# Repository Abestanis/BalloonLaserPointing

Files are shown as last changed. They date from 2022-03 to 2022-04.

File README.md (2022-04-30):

# Balloon Laser Pointing

This project is the first iteration of a laser pointing system developed as part of the
stratospheric balloon project of the M2 TSI masters at Paul Sabatier 3 University, Toulouse. 
It consists of software and structure for a two motor platform that allows to point
a laser at another balloon. The laser could then be used for communication, which is not
part of this project.

## Launch

The project was tested during the launch of a stratospheric balloon on the 23rd March 2022.
The system successfully demonstrated its pointing capabilities, although with an offset due
to calibration inaccuracies. 

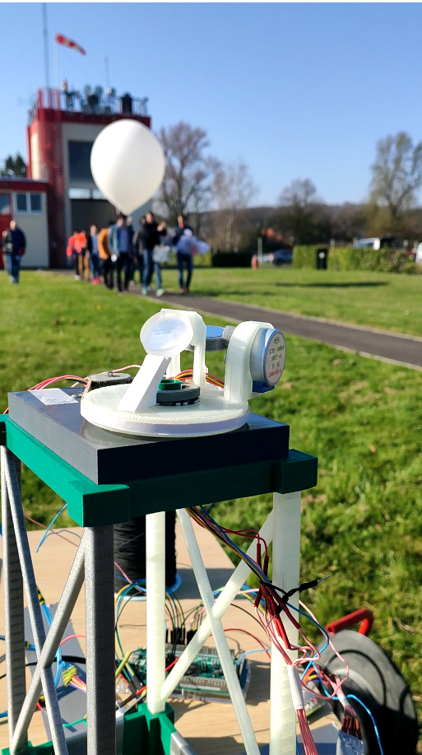
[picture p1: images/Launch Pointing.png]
Pointing during the launch aof a stratospheric balloon


## Building

The project is based on [PlatformIO](https://platformio.org). To build the project, the
[PlatformIO command line tools](https://docs.platformio.org/en/latest/core/installation.html)
are required to be installed.

Run the following commands in the top level directory of the project
(the one containing this README and the [platformio.ini](platformio.ini) file).

Initialize the project and install the dependencies:
```shell
pio project init
pio lib install
```

Build the project:
```shell
pio run
```

Build and upload the project to a connected Arduino Due:
```shell
pio run --target upload
```

## Repository structure

* [`controller`](controller): Contains the controller program that can be used to control
                              the pointing system from a computer via a serial connection.
* [`images`](images): Images used for documentation.
* [`include`](include): C/C++ header files.
* [`lib`](lib): Project specific private libraries.
* [`models`](models): The 3D models of the laser pointing structure.
* [`src`](src): The C/C++ source files containing the code of the project.
* [`platformio.ini`](platformio.ini): [PlatformIO configuration file][platformio_config].

[platformio_config]: https://docs.platformio.org/en/stable/projectconf/index.html#projectconf

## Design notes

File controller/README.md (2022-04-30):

# Controller

This directory contains a controller software that can be run on any computer which is connected
to the Arduino Due via a serial connection.

The software allows sending telecommands and to forward received GPS locations
to the Arduino.

### Dependencies

Install the dependencies with
[pip](https://packaging.python.org/en/latest/tutorials/installing-packages/#use-pip-for-installing):

```shell
pip install -r requirements.txt
```

### Running

To run the controller, start the [controller.py](controller.py) script with Python:

```shell
controller.py
```

### Telecommands

| Name | Arguments | Description |
|---|---|---|
| PING | _None_ | Send a PING, expect a PONG back. |
| GPS | latitude, longitude, altitude | Set the GPS position of the pointing target. |
| CALIBRATE_MOTORS | _None_ | Trigger the automatic calibration of the motors. |
| SET_LOCATION | latitude, longitude, altitude, orientation | Set the position and zero pointing orientation of the structure. |
| SET_MOTOR_POSITION | motor, angle | Manually set the motor position to a specific angle. |
| SET_CALIBRATION_POINT | motor | Set the calibration angle of a motor to the current angle. |

### GPS forwarding
There can be two GPS receivers connected, whose received locations will be logged.
One of the two receivers can be selected as a target in the UI.
The locations received from this GPS receiver will then be forwarded to the Arduino.

### User Interface
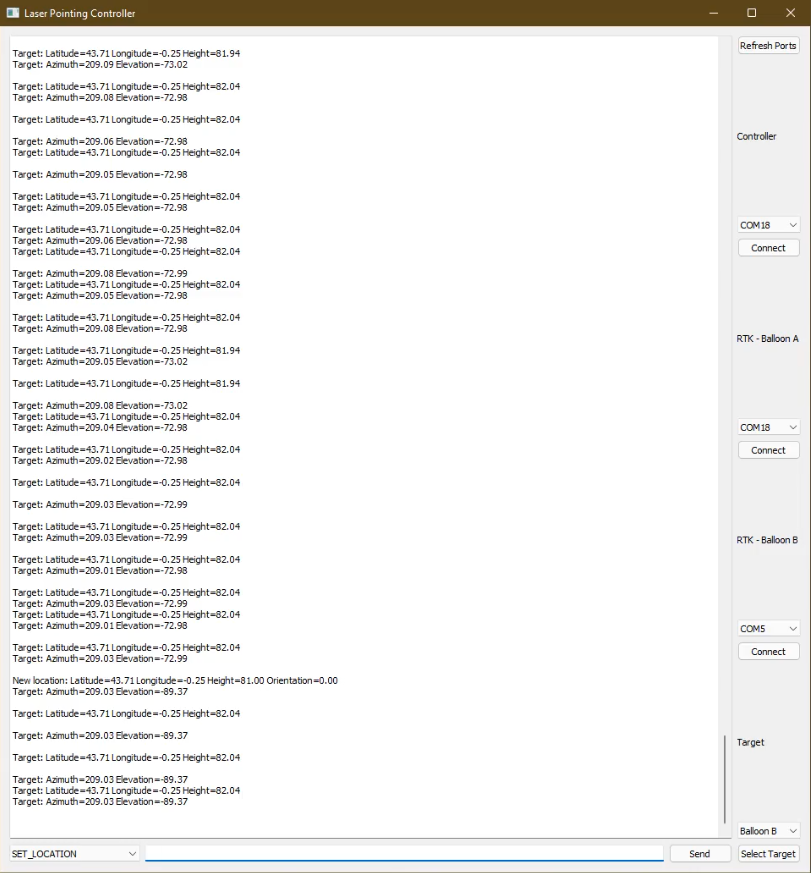
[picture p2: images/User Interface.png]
User interface screenshot


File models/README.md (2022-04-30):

# Models of the structure of the pointing system

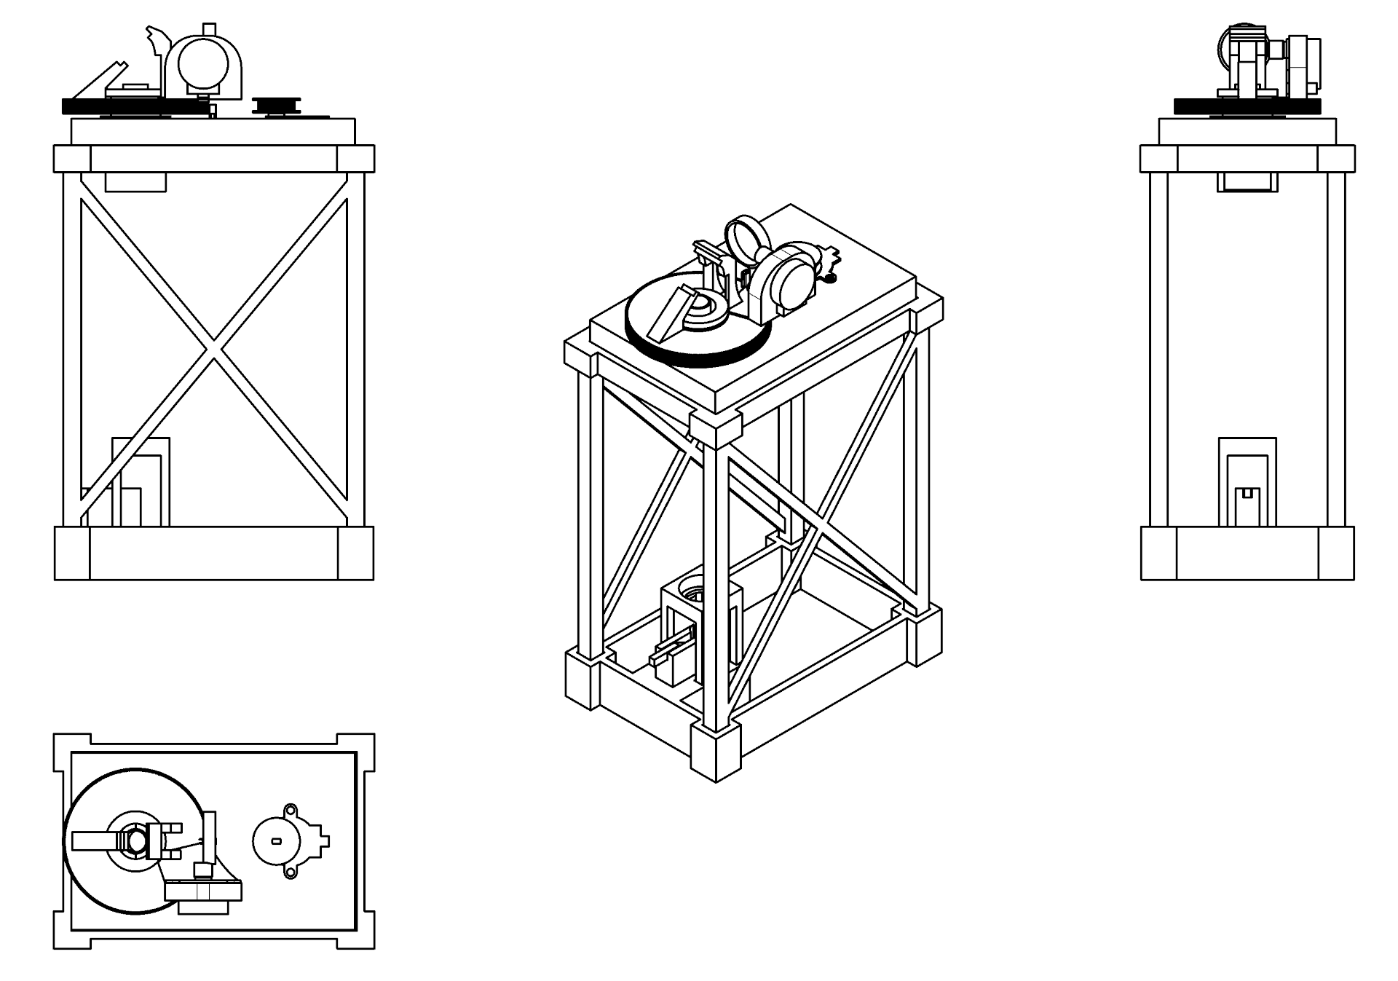
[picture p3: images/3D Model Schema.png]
The schematic of the laser pointing structure


This directory contains 3D models of all components developed for the laser pointing structure.

### Full model

The [full model](Full%20Model.stl) contains all models assembled together.

| Model | Real |
|---|---|
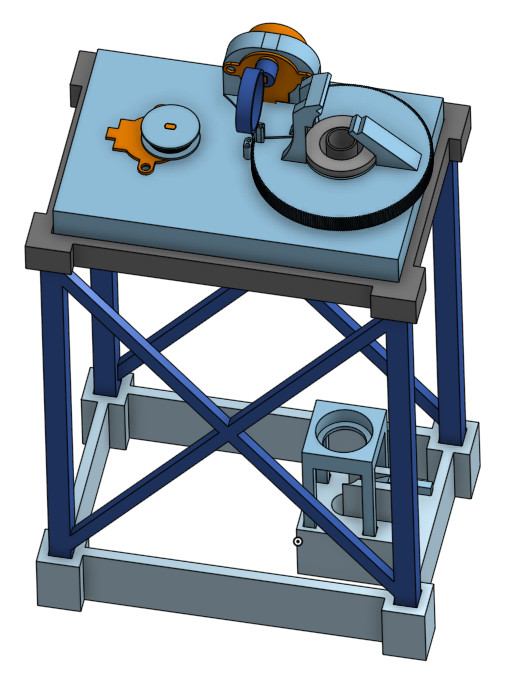
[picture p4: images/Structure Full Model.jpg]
The 3D Model of the fully assembled structure
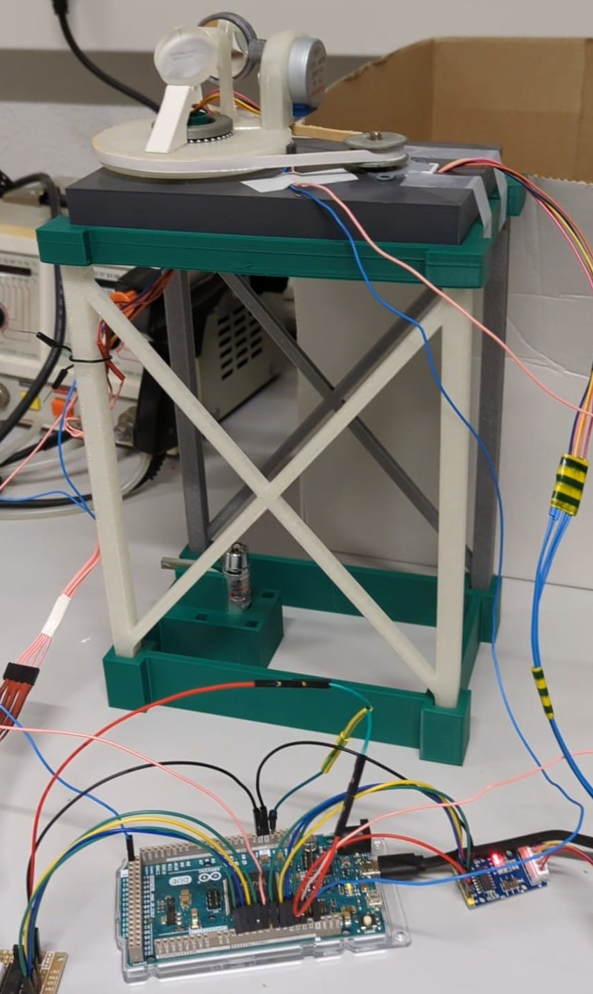
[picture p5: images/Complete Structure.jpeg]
The fully assembled structure
|  |  |

### Motor

This is a placeholder for the [actual motors][Motor Datasheet].

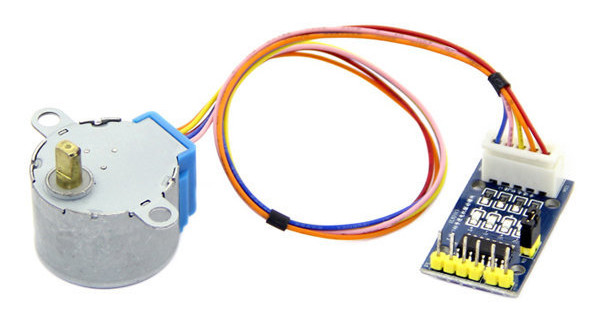
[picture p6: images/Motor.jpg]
The 28BYJ-48-08 5 Vdc motor used in the pointing system


[Motor Datasheet]: https://www.digikey.fr/fr/datasheets/mikroelektronika/mikroelektronika-step-motor-5v-28byj48-datasheet

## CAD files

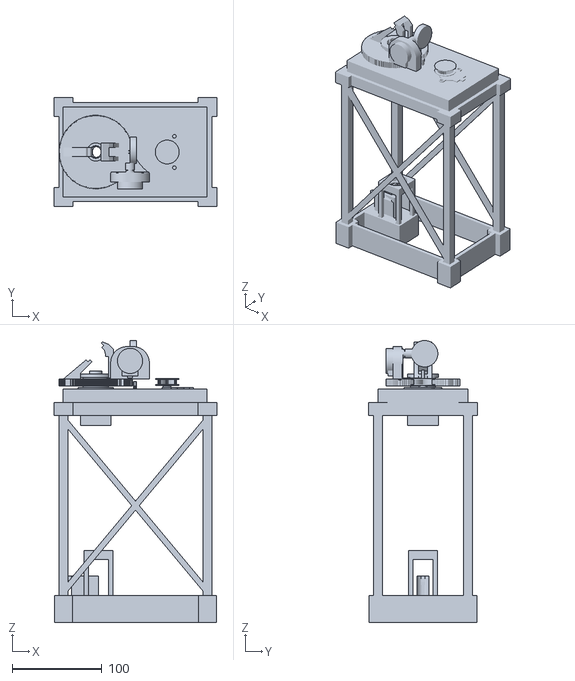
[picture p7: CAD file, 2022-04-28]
models/Full Model.stl
181.0 x 121.0 x 313.7

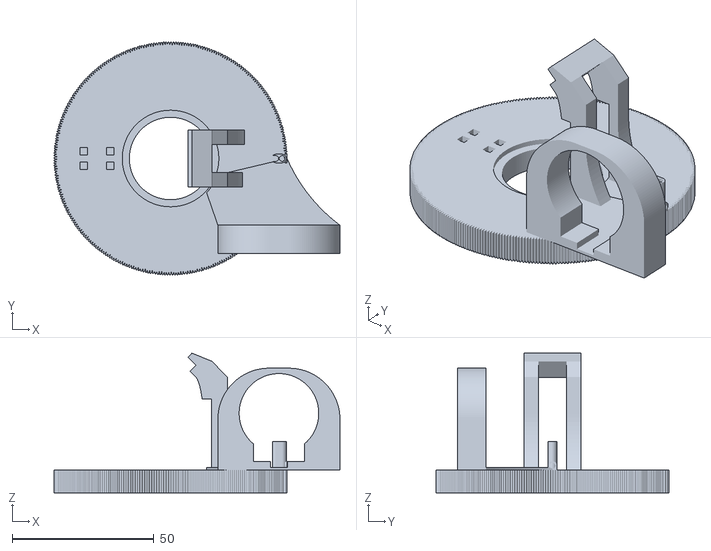
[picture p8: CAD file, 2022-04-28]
models/Main Gear.stl
100.7 x 82.1 x 49.2

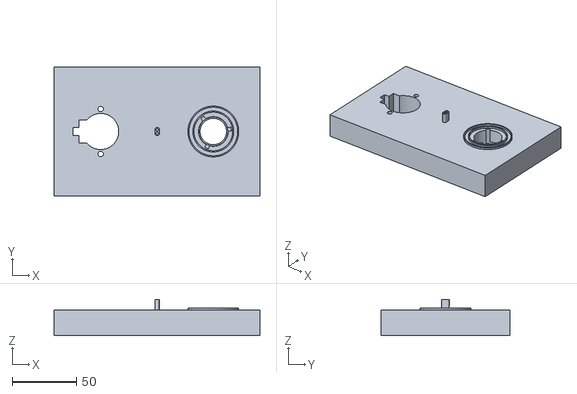
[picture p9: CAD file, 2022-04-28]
models/Motor Base.stl
160.0 x 100.0 x 28.0

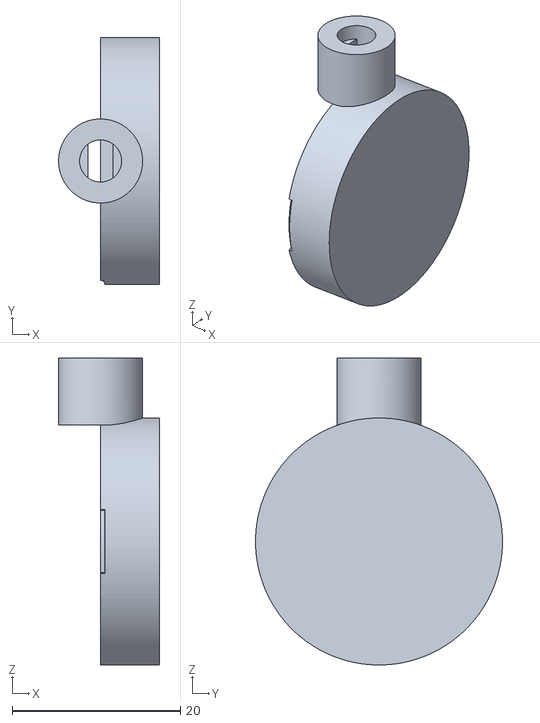
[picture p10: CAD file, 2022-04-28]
models/Mirror Ring Holder.stl
12.0 x 29.4 x 36.5

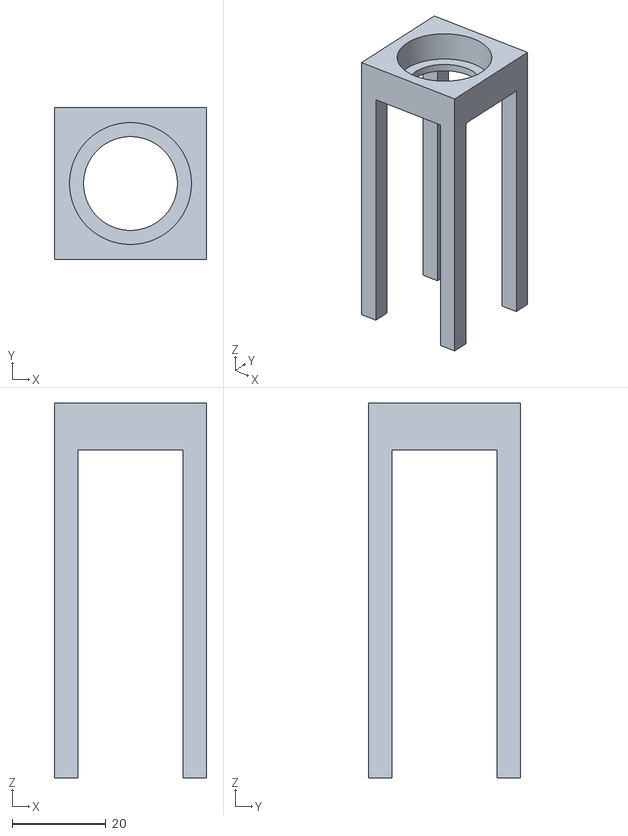
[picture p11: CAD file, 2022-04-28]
models/Lens Holder.stl
32.5 x 32.5 x 80.0

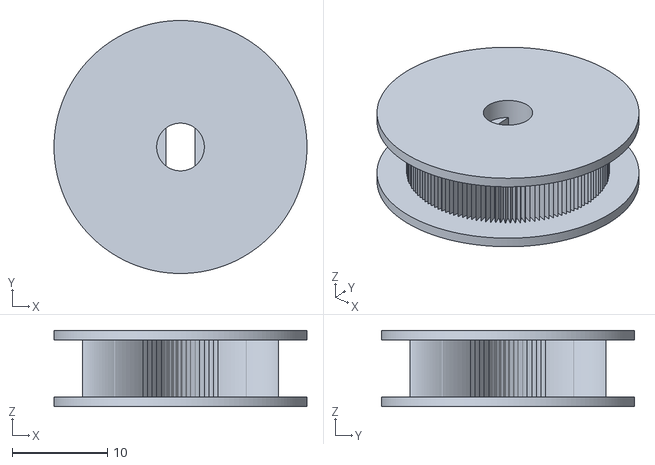
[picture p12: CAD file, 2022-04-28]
models/Small Gear.stl
26.5 x 26.5 x 8.00

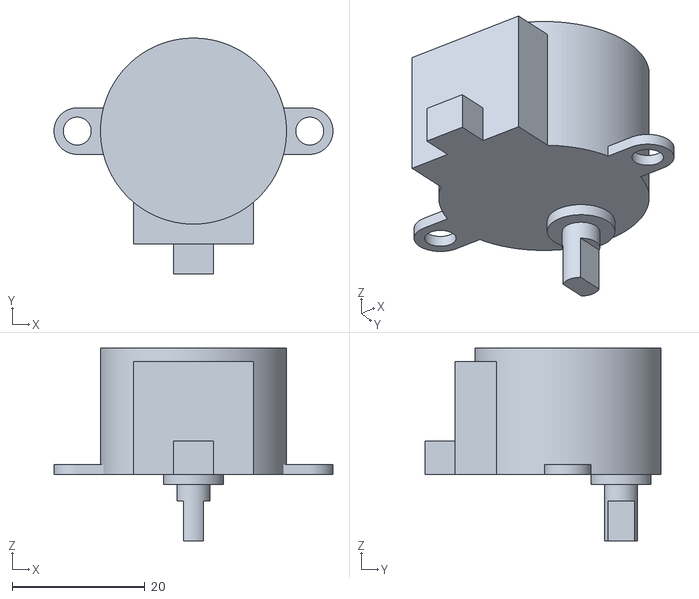
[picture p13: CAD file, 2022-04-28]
models/Motor.stl
42.0 x 35.5 x 29.0

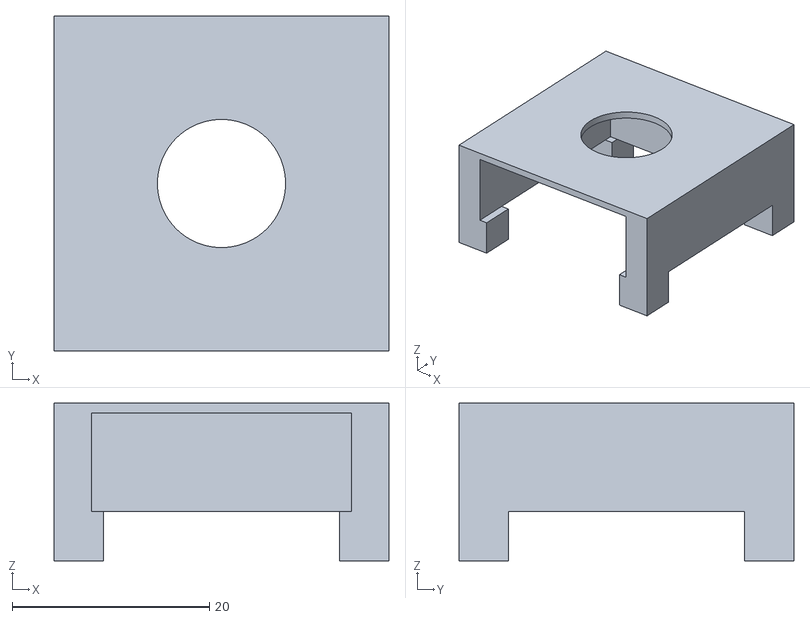
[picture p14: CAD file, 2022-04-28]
models/Lens Box.stl
34.0 x 34.0 x 16.0

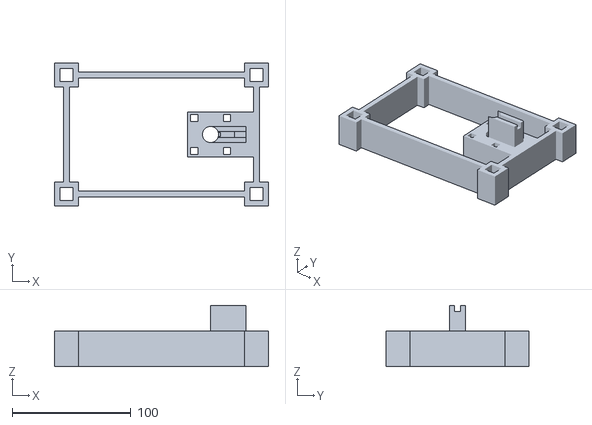
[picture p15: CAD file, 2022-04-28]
models/Base.stl
180.0 x 120.0 x 51.5

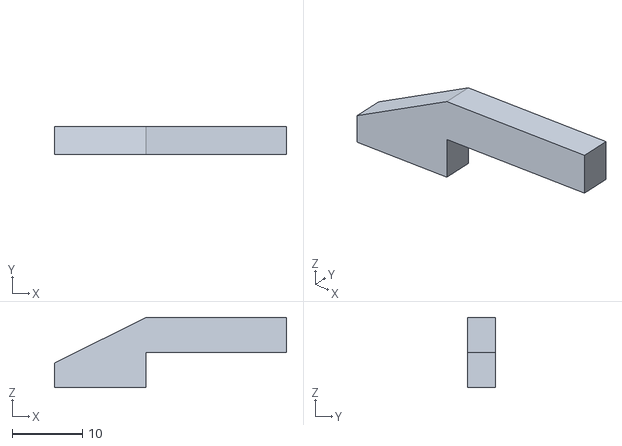
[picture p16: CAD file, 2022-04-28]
models/Laser Button Pusher.stl
33.1 x 4.00 x 10.0

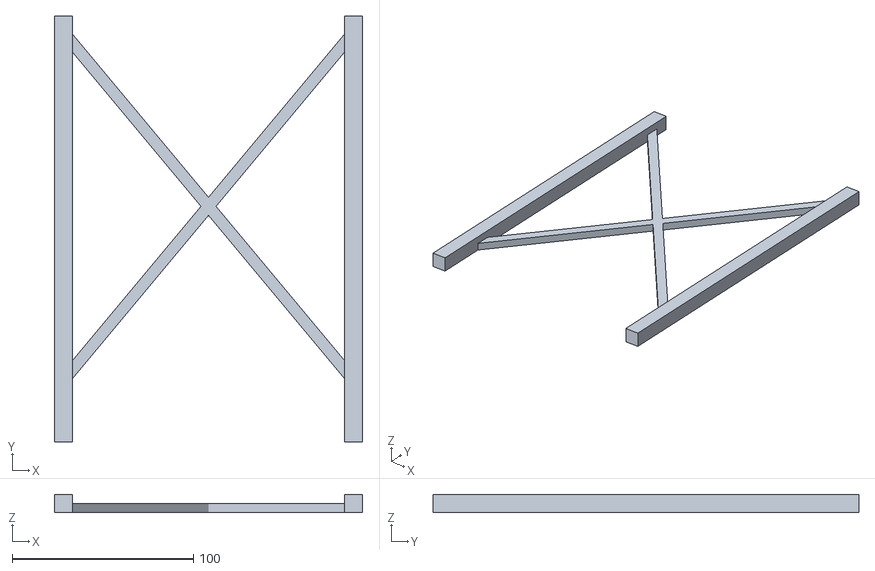
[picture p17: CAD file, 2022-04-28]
models/Pillar.stl
170.0 x 235.0 x 10.0

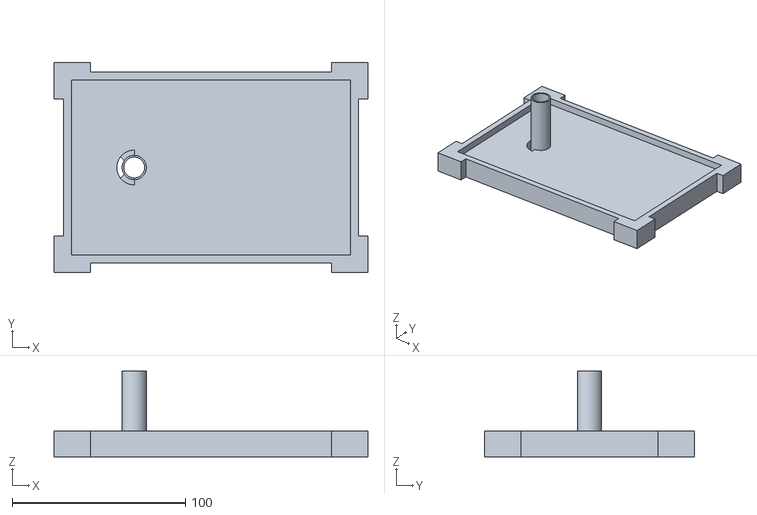
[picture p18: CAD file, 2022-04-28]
models/Top Base.stl
181.0 x 121.0 x 49.5

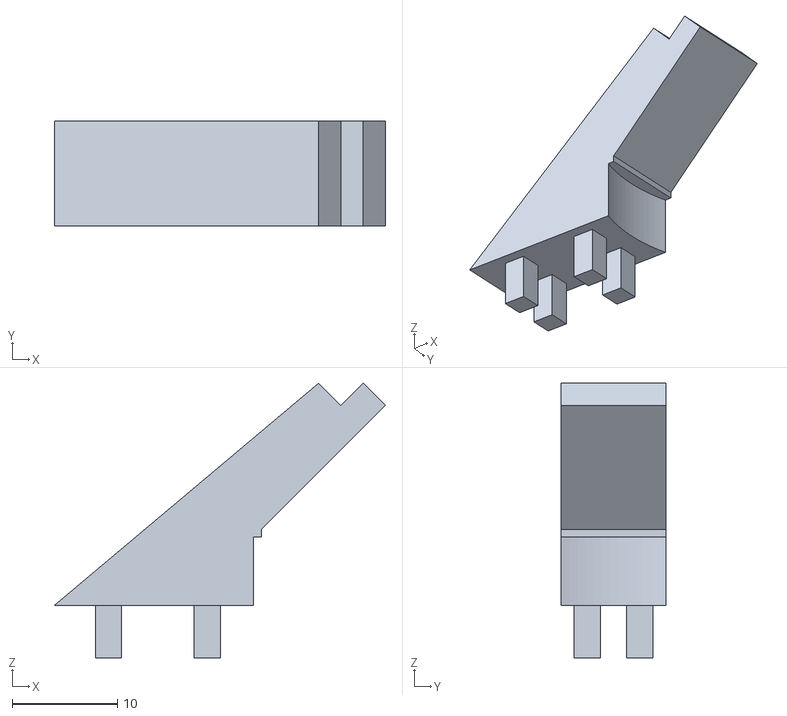
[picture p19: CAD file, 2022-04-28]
models/Mirror Holder 1.stl
31.5 x 10.0 x 26.1

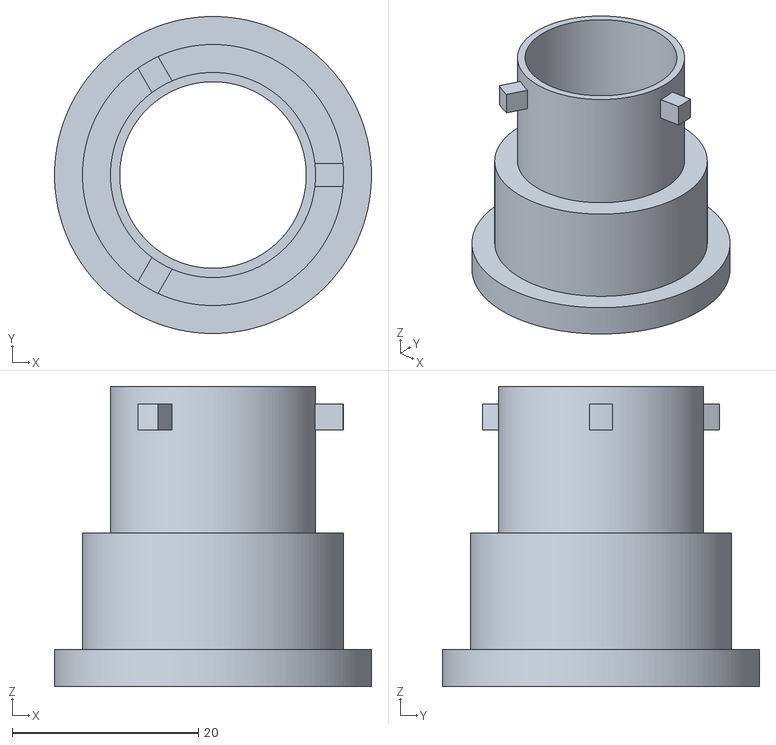
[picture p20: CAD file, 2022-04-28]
models/Gear Bolt.stl
34.0 x 34.0 x 32.2

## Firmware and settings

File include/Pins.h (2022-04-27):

/**
 * This keeps track of all pins used.
 */

#pragma once

#include <cstdint>

/**
 * A physical pin on the Arduino.
 */
class Pin {
public:
    /**
     * Create a new pin from the raw pin number.
     *
     * @param pinNumber The raw number of the pin.
     */
    explicit constexpr Pin(uint32_t pinNumber) : pinNumber(pinNumber) {
    }

    /**
     * The raw number of the pin.
     */
    const uint32_t pinNumber;
};

/**
 * All pins used in the system.
 */
class Pins {
public:
    /**
     * The first pin to control the base motor.
     */
    static constexpr Pin baseMotor1 = Pin(8);

    /**
     * The second pin to control the base motor.
     */
    static constexpr Pin baseMotor2 = Pin(9);

    /**
     * The third pin to control the base motor.
     */
    static constexpr Pin baseMotor3 = Pin(10);

    /**
     * The fourth pin to control the base motor.
     */
    static constexpr Pin baseMotor4 = Pin(11);

    /**
     * The pin indicating the 0° angle position for the base motor.
     */
    static constexpr Pin baseMotorCalibration = Pin(12);

    /**
     * The first pin to control the motor.
     */
    static constexpr Pin elevationMotor1 = Pin(3);

    /**
     * The second pin to control the elevation motor.
     */
    static constexpr Pin elevationMotor2 = Pin(4);

    /**
     * The third pin to control the elevation motor.
     */
    static constexpr Pin elevationMotor3 = Pin(5);

    /**
     * The fourth pin to control the elevation motor.
     */
    static constexpr Pin elevationMotor4 = Pin(6);

    /**
     * The pin indicating the 0° angle position for the elevation motor.
     */
    static constexpr Pin elevationMotorCalibration = Pin(7);
};

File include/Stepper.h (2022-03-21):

/**
 * A class to control a four wire stepper motor, based on the Stepper library for Wiring/Arduino.
 * Original header is included below:
 *
 * Stepper.h - Stepper library for Wiring/Arduino - Version 1.1.0
 *
 * Original library        (0.1)   by Tom Igoe.
 * Two-wire modifications  (0.2)   by Sebastian Gassner
 * Combination version     (0.3)   by Tom Igoe and David Mellis
 * Bug fix for four-wire   (0.4)   by Tom Igoe, bug fix from Noah Shibley
 * High-speed stepping mod         by Eugene Kozlenko
 * Timer rollover fix              by Eugene Kozlenko
 * Five phase five wire    (1.1.0) by Ryan Orendorff
 *
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
 *
 * Drives a unipolar, bipolar, or five phase stepper motor.
 *
 * When wiring multiple stepper motors to a microcontroller, you quickly run
 * out of output pins, with each motor requiring 4 connections.
 *
 * By making use of the fact that at any time two of the four motor coils are
 * the inverse of the other two, the number of control connections can be
 * reduced from 4 to 2 for the unipolar and bipolar motors.
 *
 * A slightly modified circuit around a Darlington transistor array or an
 * L293 H-bridge connects to only 2 microcontroler pins, inverts the signals
 * received, and delivers the 4 (2 plus 2 inverted ones) output signals
 * required for driving a stepper motor. Similarly the Arduino motor shields
 * 2 direction pins may be used.
 *
 * The sequence of control signals for 5 phase, 5 control wires is as follows:
 *
 * Step C0 C1 C2 C3 C4
 *    1  0  1  1  0  1
 *    2  0  1  0  0  1
 *    3  0  1  0  1  1
 *    4  0  1  0  1  0
 *    5  1  1  0  1  0
 *    6  1  0  0  1  0
 *    7  1  0  1  1  0
 *    8  1  0  1  0  0
 *    9  1  0  1  0  1
 *   10  0  0  1  0  1
 *
 * The sequence of control signals for 4 control wires is as follows:
 *
 * Step C0 C1 C2 C3
 *    1  1  0  1  0
 *    2  0  1  1  0
 *    3  0  1  0  1
 *    4  1  0  0  1
 *
 * The sequence of controls signals for 2 control wires is as follows
 * (columns C1 and C2 from above):
 *
 * Step C0 C1
 *    1  0  1
 *    2  1  1
 *    3  1  0
 *    4  0  0
 *
 * The circuits can be found at
 *
 * http://www.arduino.cc/en/Tutorial/Stepper
 */

#pragma once

#include <cstdint>
#include <vector>
#include <DueTimer.h>
#include "units.h"
#include "Pins.h"


/**
 * A stepper motor that can freely rotate in 360 degrees.
 */
class Stepper {
public:

    /**
     * Initialize a stepper motor and start the calibration routine.
     *
     * @param numberOfSteps The number of steps that the motor can take per revolution.
     * @param stepDelay The delay between steps in microseconds.
     * @param motorPin1 The pin number of the first connection to the motor.
     * @param motorPin2 The pin number of the second connection to the motor.
     * @param motorPin3 The pin number of the third connection to the motor.
     * @param motorPin4 The pin number of the fourth connection to the motor.
     * @param calibrationPin The pin number used for calibration of the zero angle of the motor.
     */
    Stepper(unsigned int numberOfSteps, unsigned long stepDelay, Pin motorPin1, Pin motorPin2,
            Pin motorPin3, Pin motorPin4, Pin calibrationPin);

    /**
     * Stop and destruct the motor.
     */
    ~Stepper();

    /**
     * Set the target angle of the motor.
     *
     * @note The function will block until the motor reached the target angle.
     * @param angle The target angle in degrees.
     */
    void setTargetAngle(deg_t angle);

    /**
     * Asynchronously determine the reference step (0° angle) of the motor.
     */
    void calibrate();

    /**
     * Set the current orientation as the calibration point.
     */
    void setCurrentAsCalibrationPoint();

private:
    /**
     * Timer handler that updates the current step towards the target step.
     */
    static void updateMotors();

    /**
     * Update the motor and advance to the next step towards the target step.
     */
    void updateStep();

    /**
     * Set the current step of the motor.
     *
     * @param step The step to step to.
     */
    void setStep(unsigned int step);

    /**
     * Convert an angle in degrees to the corresponding step.
     *
     * @param angle The angle in degrees.
     * @return The step corresponding to the angle.
     */
    unsigned int getStepForAngle(deg_t angle) const;

    /**
     * The delay in microseconds between steps.
     */
    unsigned long stepDelay;

    /**
     * The total number of steps that the motor can take.
     */
    unsigned int totalSteps;

    /**
     * The angle that the motor should point to in degrees.
     */
    deg_t targetAngle = deg_t(0);

    /**
     * The step of the motor that is targeted by the targetAngle.
     */
    unsigned int targetStep = 0;

    /**
     * The current step the motor is on.
     */
    unsigned int currentStep = 0;

    /**
     * Reference step for an angle of zero.
     */
    unsigned int referenceStep;

    /**
     * The current step when the calibration was requested.
     */
    unsigned int calibrationStartStep = 0;

    /**
     * The pin for the first connection to the motor.
     */
    Pin motorPin1;

    /**
     * The pin for the second connection to the motor.
     */
    Pin motorPin2;

    /**
     * The pin for the third connection to the motor.
     */
    Pin motorPin3;

    /**
     * The pin for the fourth connection to the motor.
     */
    Pin motorPin4;

    /**
     * The pin used for calibration.
     */
    Pin calibrationPin;
    /**
     * The time stamp in microseconds when the last step was taken.
     */
    uint32_t lastStepTime = 0;

    /**
     * The timer used to drive this motor.
     */
    DueTimer timer;
};

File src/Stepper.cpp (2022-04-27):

#include <cmath>
#include <algorithm>
#include "arduinoSystem.h"
#include "Stepper.h"

/** The maximum amount of jitter allowed for the motor update timer in microseconds. */
#define MAX_TIMER_JITTER_MICRO_SEC 10

static std::vector<Stepper*> stepperMotors = {};


Stepper::Stepper(unsigned int numberOfSteps, unsigned long stepDelay, Pin motorPin1, Pin motorPin2,
                 Pin motorPin3, Pin motorPin4, Pin calibrationPin) :
        stepDelay(stepDelay), totalSteps(numberOfSteps), referenceStep(0),
        motorPin1(motorPin1), motorPin2(motorPin2), motorPin3(motorPin3), motorPin4(motorPin4),
        calibrationPin(calibrationPin), timer(DueTimer::getAvailable()) {

    // Set up the pins on the microcontroller.
    pinMode(this->motorPin1.pinNumber, OUTPUT);
    pinMode(this->motorPin2.pinNumber, OUTPUT);
    pinMode(this->motorPin3.pinNumber, OUTPUT);
    pinMode(this->motorPin4.pinNumber, OUTPUT);
    pinMode(this->calibrationPin.pinNumber, INPUT_PULLUP);

    stepperMotors.push_back(this);
    this->timer.attachInterrupt(&Stepper::updateMotors).start(stepDelay);
}

Stepper::~Stepper() {
    this->timer.stop();
    (void) std::remove(stepperMotors.begin(), stepperMotors.end(), this);
}

void Stepper::setTargetAngle(deg_t angle) {
    if (std::isnan(angle.value)) {
        Serial.println("Rejecting NaN target angle!");
        return;
    }
    this->targetAngle = angle;
    this->targetStep = getStepForAngle(this->targetAngle);
}

void Stepper::updateMotors() {
    uint32_t now = micros();
    for (auto& motor: stepperMotors) {
        if (now - motor->lastStepTime > motor->stepDelay - MAX_TIMER_JITTER_MICRO_SEC
            || now < motor->lastStepTime) {
            motor->updateStep();
            motor->lastStepTime = now;
        }
    }
}

void Stepper::calibrate() {
    this->calibrationStartStep = this->currentStep;
    this->referenceStep = this->totalSteps;
}

void Stepper::updateStep() {
    if (this->referenceStep == this->totalSteps) {
        if (digitalRead(this->calibrationPin.pinNumber) == HIGH) {
            setStep((this->currentStep + 1) % this->totalSteps);
            if (this->currentStep == this->calibrationStartStep) {
                // TODO: This is a temporary fix to prevent the motor from spinning more than 360°
                //       Remove this when the restrictions are added elsewhere.
                Serial.print("Calibration failed...\n");
                this->referenceStep = this->currentStep;
            }
            return;
        }
        Serial.print("Calibration complete...\n");
        this->referenceStep = this->currentStep;
    }
    if (this->targetStep != this->currentStep) {
        bool increasing = this->currentStep < this->targetStep ?
                          this->targetStep - this->currentStep <
                          this->totalSteps - this->targetStep + this->currentStep :
                          this->currentStep - this->targetStep >
                          this->totalSteps - this->currentStep + this->targetStep;
        unsigned int newStep;
        if (increasing) {
            newStep = this->currentStep + 1;
            if (newStep == this->totalSteps) {
                newStep = 0;
            }
        } else if (this->currentStep == 0) {
            newStep = this->totalSteps;
        } else {
            newStep = this->currentStep - 1;
        }
        setStep(newStep);
    }
}

void Stepper::setStep(unsigned int step) {
    switch (step % 4) {
    case 0:  // 1100
        digitalWrite(this->motorPin1.pinNumber, HIGH);
        digitalWrite(this->motorPin2.pinNumber, HIGH);
        digitalWrite(this->motorPin3.pinNumber, LOW);
        digitalWrite(this->motorPin4.pinNumber, LOW);
        break;
    case 1:  // 0110
        digitalWrite(this->motorPin1.pinNumber, LOW);
        digitalWrite(this->motorPin2.pinNumber, HIGH);
        digitalWrite(this->motorPin3.pinNumber, HIGH);
        digitalWrite(this->motorPin4.pinNumber, LOW);
        break;
    case 2:  //0011
        digitalWrite(this->motorPin1.pinNumber, LOW);
        digitalWrite(this->motorPin2.pinNumber, LOW);
        digitalWrite(this->motorPin3.pinNumber, HIGH);
        digitalWrite(this->motorPin4.pinNumber, HIGH);
        break;
    case 3:  //1001
        digitalWrite(this->motorPin1.pinNumber, HIGH);
        digitalWrite(this->motorPin2.pinNumber, LOW);
        digitalWrite(this->motorPin3.pinNumber, LOW);
        digitalWrite(this->motorPin4.pinNumber, HIGH);
        break;
    }
    this->currentStep = step;
}

unsigned int Stepper::getStepForAngle(deg_t angle) const {
    return (lround((this->totalSteps - 1) / 360.0 * angle.value) + this->referenceStep) %
           this->totalSteps;
}

void Stepper::setCurrentAsCalibrationPoint() {
    this->referenceStep = this->currentStep;
}

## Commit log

2021-12-03 Add support for reading the gyroscope of the IMU and compensating the rotation
    This has not been tested.
2021-12-09 Include a modified version of the stepper library that allows setting a target angle
    This avoids drift by not using a rounded angle as the target step.
    [Stepper.cpp, Stepper.h]
2021-12-10 Use the correct library for the IMU
    [imu.cpp]
2021-12-10 Use a timer to drive the motor
2022-03-02 Library for Light Sensors
2022-03-14 Add an arduinoSystem header to work around min/max macro problems
    [Stepper.cpp]
2022-03-14 Add a parser for GPS messages
    This will allow us to receive locations of our pointing target
    and forward them to the Arduino.
2022-03-15 Move the light sensor code into a separate directory to fix the build
2022-03-16 Add calibration function for both motors
2022-03-16 Set the pin mode of the calibration pin and fix the build
    [Stepper.cpp, Stepper.h]
2022-03-16 Make the motor calibration asynchronous
    This means that the two motors can be synchronized simultaneously.
2022-03-17 Add a motor calibration command
2022-03-17 Add a pin type and track all used pins in a class
2022-03-17 Configure the calibration input as pull-up
    This avoids floating the pin when the line is not connected.
    [Stepper.cpp]
2022-03-17 Store the laser and target position in the Program class
2022-03-17 Add missing include to Pins.h
    [Pins.h]
2022-03-19 Add second motor
2022-03-20 Fix stepper motor calibration check
    [Stepper.cpp]
2022-03-20 Remove the old reference frame conversion functions
2022-03-20 Use the new transformation functions to calculate the motor angles
2022-03-21 Disable IMU support
2022-03-21 Add SET_MOTOR_POSITION command
    This command allows to control the motors manually.
2022-03-21 Add SET_CALIBRATION_POINT command
    This command allows to set the current orientation
    of a motor as it's calibration point (0 degree).
2022-03-21 Send the last known location of the new target when switching
2022-03-21 Disable automatic motor calibration at startup
2022-03-21 Fix generating a Nan elevation for edge cases
    Due to floating point rounding errors, the argument to acos
    could sometimes be greater than 1. Clamp the value in that case.
2022-03-21 Reject NaN values in Stepper::setTargetAngle
2022-03-21 Adjust the way the pointing works
    Previously, when viewed from the side, we used the first quadrant
    for the elevation:
    ^ <-.
    | \ Elevation
    | |
    | v
    -------+--------->
    Now we use the fourth quadrant:
    .-> ^
    Elevation / |
    | |
    v |
    -----------+------>
    This has the advantage that we are no longer obstructed by the
    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
    [Program.cpp]
2022-03-21 Compensate for base motors the gear ratio
2022-03-21 Add some feedback during manual calibration
2022-03-22 Add a refresh ports button
2022-03-22 Handle serial errors in the laser pointing connection
2022-03-22 Add the height offsets for both balloons
    The height difference between the GPS receiver and the
    light sensor is 26 cm on both.
2022-03-22 Write all received data from the laser pointing system into a log file
2022-03-22 Fix inserting into the log text widget
2022-04-06 Fix the case when a selected com port was removed
2022-04-27 Prevent motors being stuck after 70 minutes
    micros() overflows after 70 minutes, (now - motor->lastStepTime)
    would always be negative in that case.
    [Stepper.cpp]
2022-04-27 Remove the light sensor code
    The up-to-date code is bundled with the code of the two balloons.
2022-04-28 Add the 3D laser pointing structure models
    [Base.stl, Full Model.stl, Gear Bolt.stl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]
